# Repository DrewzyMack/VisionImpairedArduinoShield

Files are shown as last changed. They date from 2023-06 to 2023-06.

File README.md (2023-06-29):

# Vision Impaired Arduino Shield
An Arduino Shield designed for a vision impaired student in my robotics class.

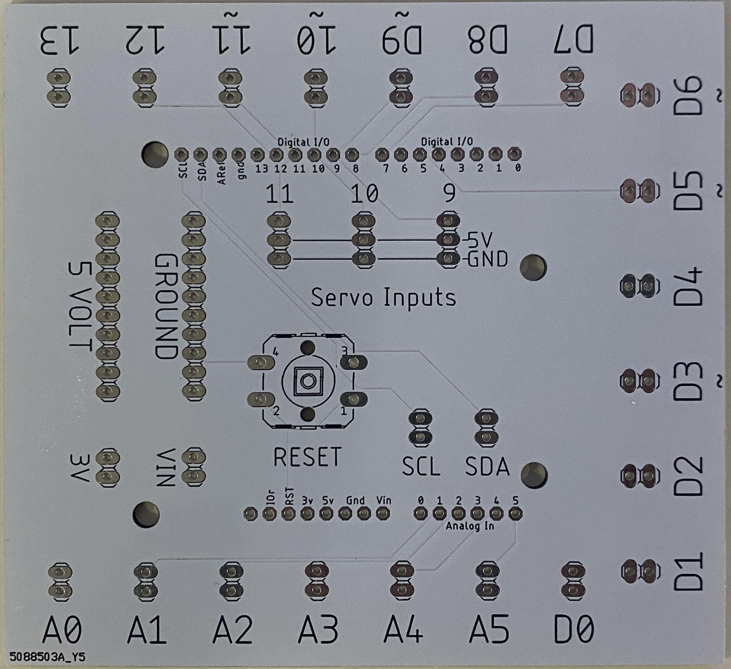
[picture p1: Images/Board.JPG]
Example Image of Shield


## General Info
This was designed for a vision impaired student in my robotics class, as we decided the pin spacing on an Arduino was too close together.

Feel free to download the EAGLE files and customise it however you like.

If you just want to get one made, download the GERBER .zip file and send it right off to your preferred PCB manufacturer. (I used JLCPCB and got it made in their white soldermask with a black silkscreen to maximise contrast)

## Bill of Materials
| Part | Quantity | Notes |
|---|---|---|
| 1x2 Female Pin Header | 24 | |
| 1x3 Female Pin Header | 3 | |
| 1x10 Female Pin Header | 2 | |
| 1x32 Male Pin Header | 1 | Broken into lengths of 10, 8, 8 and 6 |
| 12mm Tactile Switch | 1 | |

## Images

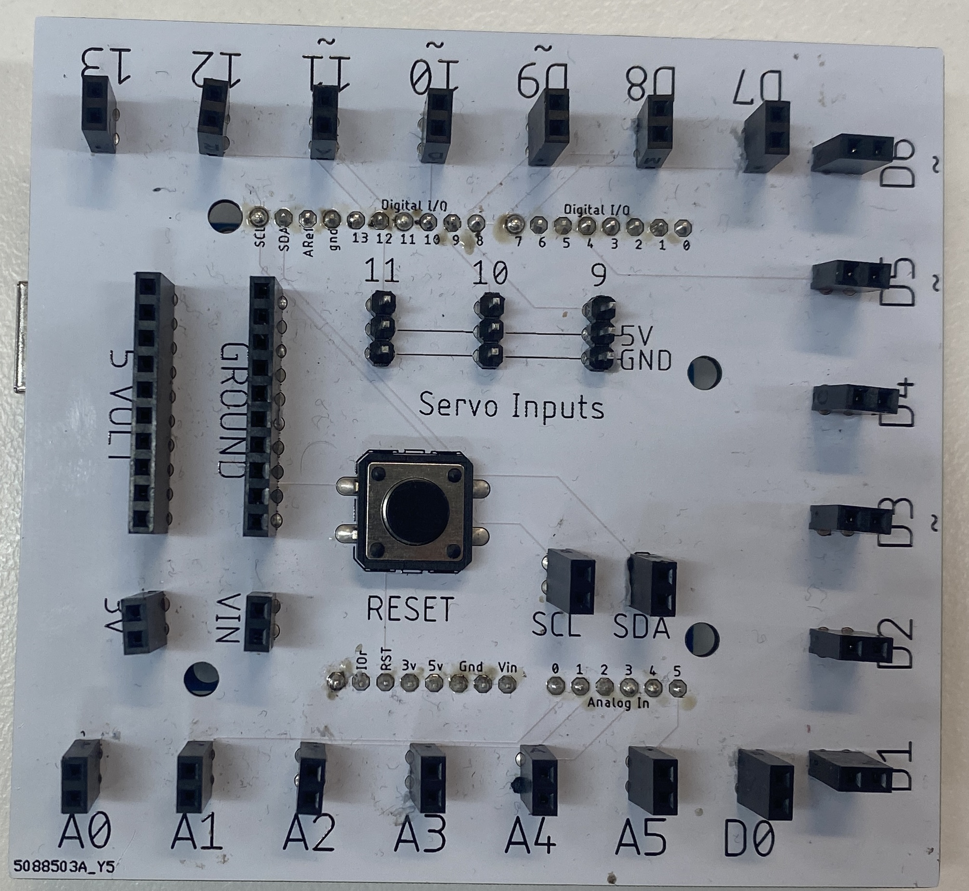
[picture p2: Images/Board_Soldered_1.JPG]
Image of soldered board


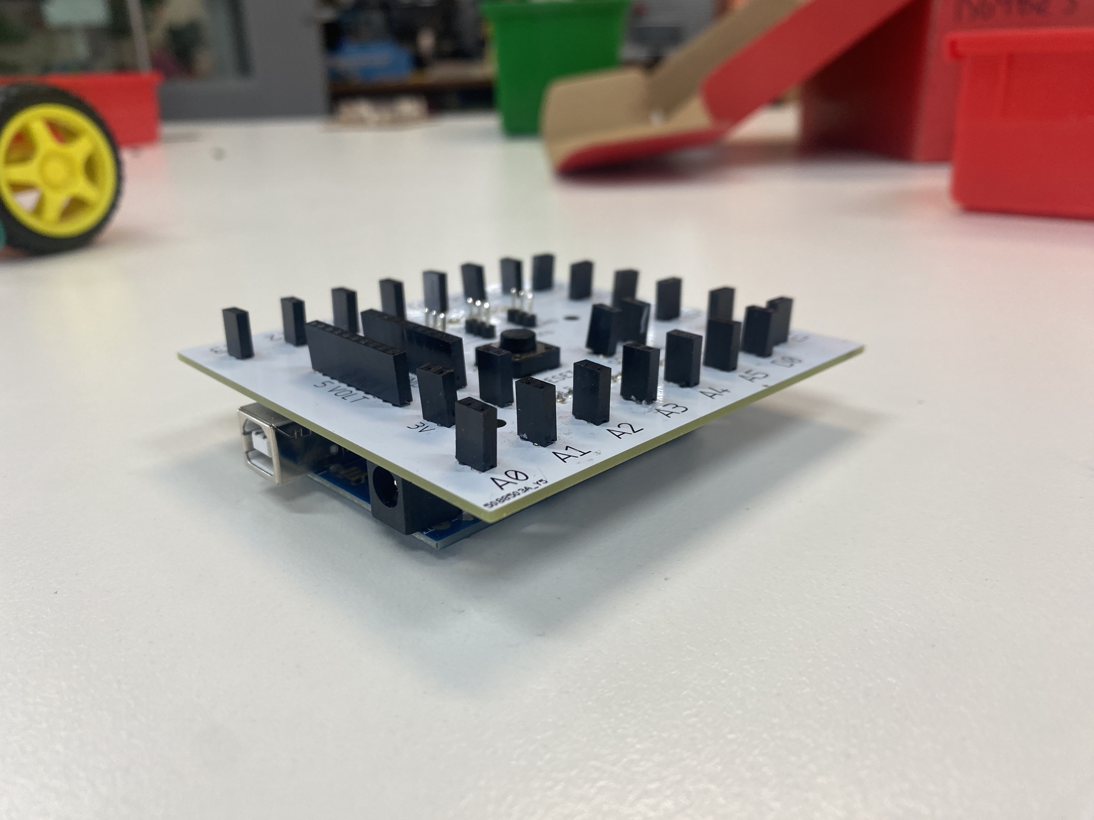
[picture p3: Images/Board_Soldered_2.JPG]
Image of soldered board


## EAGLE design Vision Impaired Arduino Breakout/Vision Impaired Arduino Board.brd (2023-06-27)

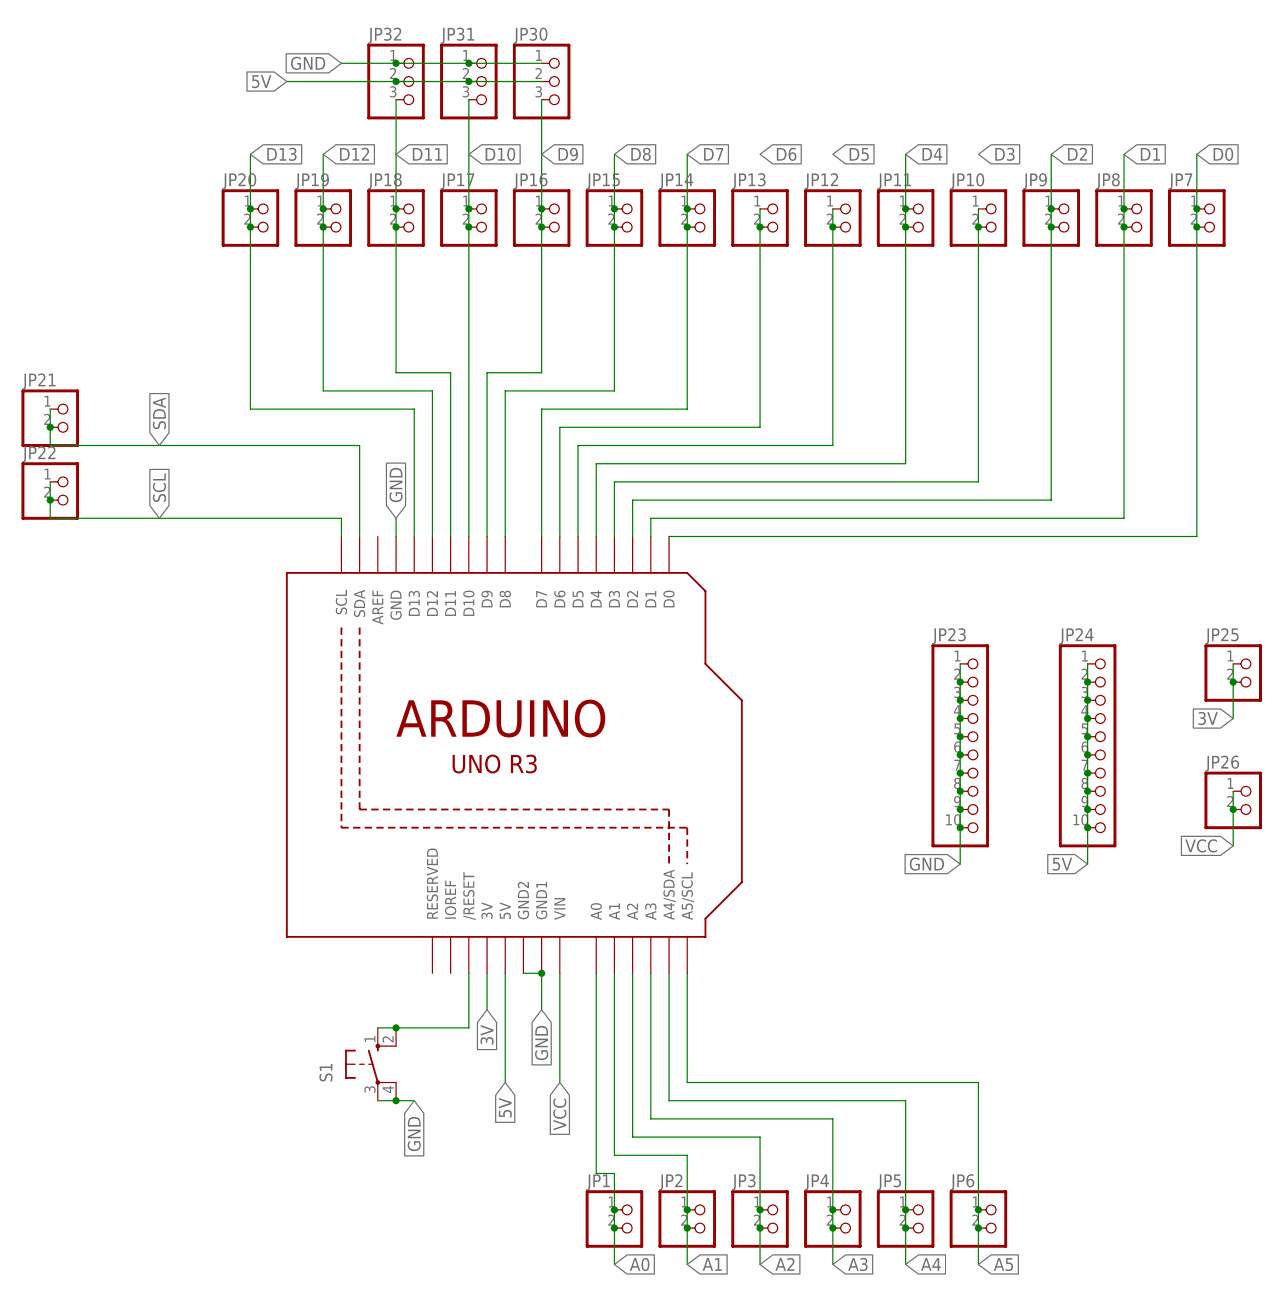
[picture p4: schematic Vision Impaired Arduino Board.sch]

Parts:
JP1, JP2, JP3, JP4, JP5, JP6, JP7, JP8, JP9, JP10, JP11, JP12, JP13, JP14, JP15, JP16, JP17, JP18, JP19, JP20, JP21, JP22, JP25, JP26: PINHD-1X2; 1X02
JP23, JP24: PINHD-1X10; 1X10
JP30, JP31, JP32: PINHD-1X3; 1X03
S1: 40-XX; B3F-40XX
U1: ARDUINOR3-BPLACE

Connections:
3V: JP25.1, JP25.2, U1.3V
5V: JP24.1, JP24.2, JP24.3, JP24.4, JP24.5, JP24.6, JP24.7, JP24.8, JP24.9, JP24.10, JP30.2, JP31.2, JP32.2, U1.5V
A0: JP1.1, JP1.2, U1.A0
A1: JP2.1, JP2.2, U1.A1
A2: JP3.1, JP3.2, U1.A2
A3: JP4.1, JP4.2, U1.A3
A4: JP5.1, JP5.2, U1.A4 (A4/SDA)
A5: JP6.1, JP6.2, U1.A5 (A5/SCL)
D0: JP7.1, JP7.2, U1.D0
D1: JP8.1, JP8.2, U1.D1
D2: JP9.1, JP9.2, U1.D2
D3: JP10.1, JP10.2, U1.D3
D4: JP11.1, JP11.2, U1.D4
D5: JP12.1, JP12.2, U1.D5
D6: JP13.1, JP13.2, U1.D6
D7: JP14.1, JP14.2, U1.D7
D8: JP15.1, JP15.2, U1.D8
D9: JP16.1, JP16.2, JP30.3, U1.D9
D10: JP17.1, JP17.2, JP31.3, U1.D10
D11: JP18.1, JP18.2, JP32.3, U1.D11
D12: JP19.1, JP19.2, U1.D12
D13: JP20.1, JP20.2, U1.D13
GND: JP23.1, JP23.2, JP23.3, JP23.4, JP23.5, JP23.6, JP23.7, JP23.8, JP23.9, JP23.10, JP30.1, JP31.1, JP32.1, S1.3, S1.4 (P1), U1.GND, U1.GND1, U1.GND2
unnamed: S1.1 (S), S1.2 (S1), U1.RESET (/RESET)
SCL: JP22.1, JP22.2, U1.SCL
SDA: JP21.1, JP21.2, U1.SDA
VCC: JP26.1, JP26.2, U1.VIN

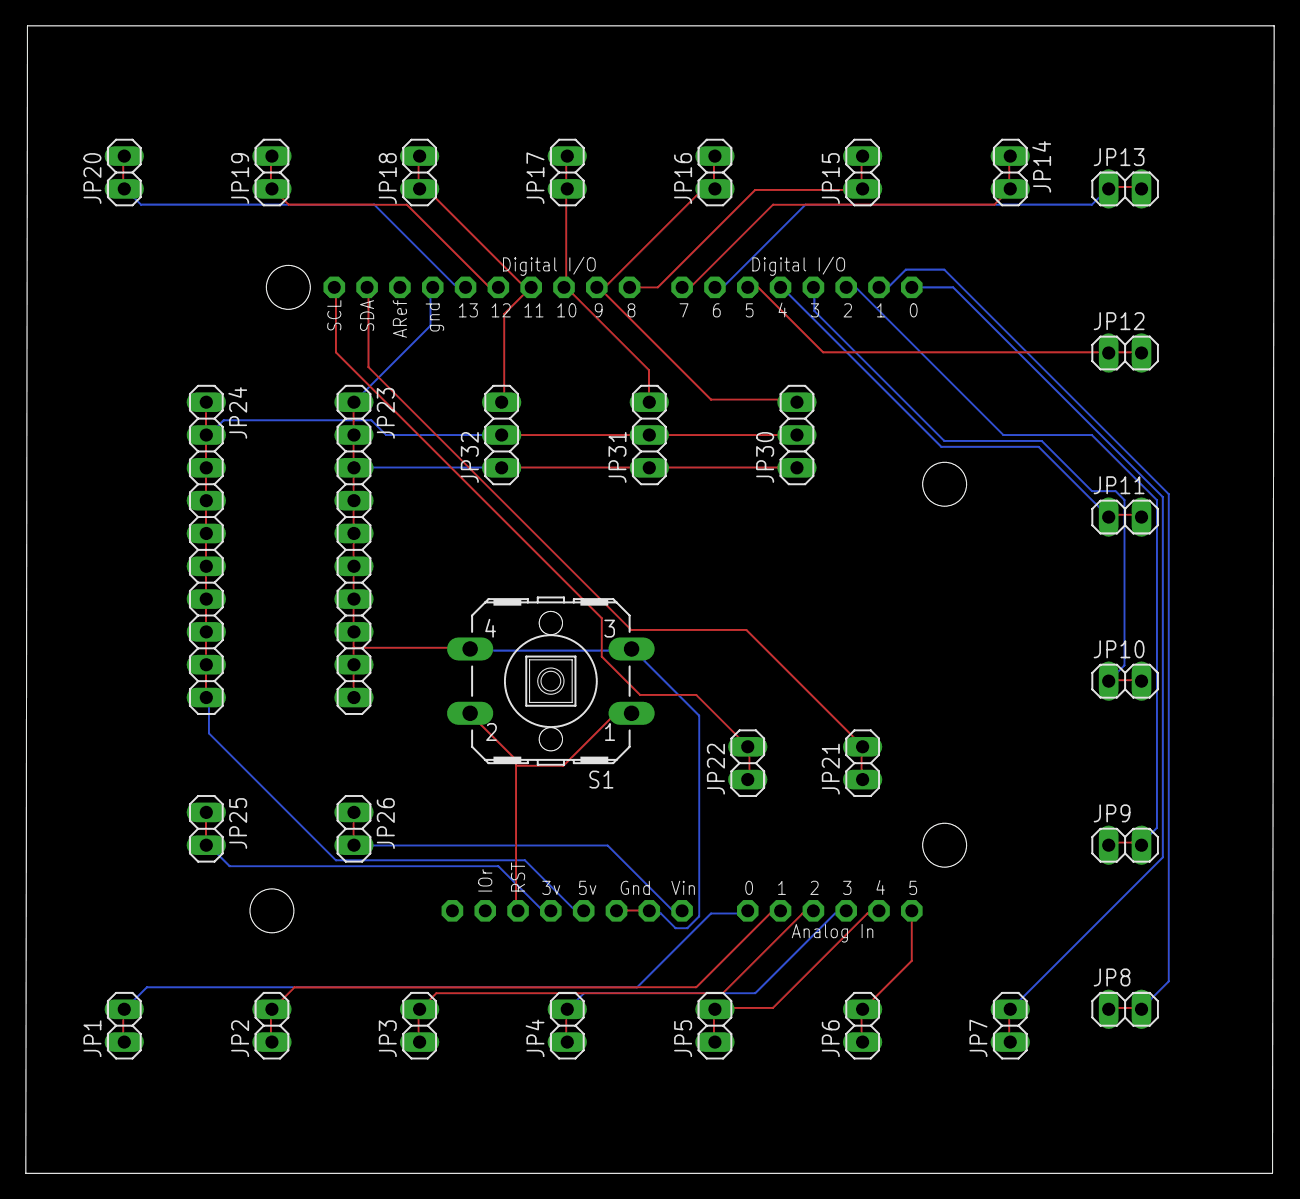
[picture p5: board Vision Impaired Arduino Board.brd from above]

Board: 2 copper layers, 96.6 x 88.8 mm, 31 parts (0 on the bottom side), 27 nets.

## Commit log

2023-06-27 Cropped board images
2023-06-27 Added Eagle & Gerber Files
    [Vision Impaired Arduino Board.brd, Vision Impaired Arduino Board.sch]
